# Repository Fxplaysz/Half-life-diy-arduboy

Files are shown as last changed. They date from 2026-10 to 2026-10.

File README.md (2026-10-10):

# Half-life-diy-arduboy
Hello everyone, this is my repository for my diy arduboy. Here you'll find the pcb and the 3d models later on.
I have made this DIY arduboy because i like mini handheld game consoles and electronics. This DIY Arduboy is very easy to build and can be made by anyone easily.

Aruduboy is a open source game console made by Kevin Bates. He has opensourced his console and made it easier for anyone to build it and have fun with it. I remember a few years back i tried making it by myself but i failed in doing so because of the technicalities in building it. So i've decided to make this project to let anyone make a DIY Arduboy easily and have fun while doing it.

It was made using KiCad and with the help of the internet. 
I made it in 2 days in the span of 5 hours in the 2 days.

# Features
* 0.96 SPI OLED display
* ISP pins for easy programming
* Buzzer for audio
* Flash chip to store more then 500+ games
* RGB LED
* *Silent* SMD push button switches. Good for long term gaming.

# Instructions
* Flash [Arduboy bootloader](https://github.com/MrBlinky/Arduboy-homemade-package) using the ISP header and a [usb asp](https://robu.in/product/usbasp-avr-programming-device-for-atmel-proccessors/)
* Upload games using the cart builder from MrBlinky [Arduboy-Python-Utilities](https://github.com/MrBlinky/Arduboy-Python-Utilities)
* Start Playing with it!

  - *More detailed instructions will be uploaded later*
    
# Photos
These are some of the photos of my PCBs.
1) PCB with smd mounted flash chip.
- Front
diy_ardubo_front

- Back
diy_ardubo_back

* PCB Lay out


2) PCB with support for flash module.
- Front
diy_ardubo_flash_module_front

- Back
diy_ardubo_flash_module_back

* PCB Lay out
  

   - [DIY Arduboy with Flash Module support](https://github.com/Fxplaysz/Half-life-diy-arduboy/blob/main/diy_ardubo_flash_module.pdf)
   - [DIY Arduboy with SMD flash chip](https://github.com/Fxplaysz/Half-life-diy-arduboy/blob/main/diy_ardubo.pdf)

The flash module version supports the addition of a flash module instead of using smd flash chip. Its mainly through hole components making it easier to build and use it.

The SMD version is a little slimmer then the flash module version but its hard to solder without hot air gun. So the choice is yours to build. 

Anyone Interested in building it can check my [BOM list](https://github.com/Fxplaysz/Half-life-diy-arduboy/blob/main/BOM.md). Feel free to ask questions.
Have fun everyone!

**Firmware Credit:** The test firmware used for this project is [Back to the Jungle](https://github.com/eried/ArduboyBackToTheJungle) created by **eried**.

* **Arduboy community:** https://community.arduboy.com/

* **Arduboy:** https://www.arduboy.com/

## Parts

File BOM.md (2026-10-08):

# DIY arduboy – bill of materials

<!-- Generated by Half Life from project cmuv6l7gq0e3701smizq8m7ku. Edits here are overwritten on the next sync. -->
<!-- Generated: 2026-10-08T20:18:28.352Z -->

> [!NOTE]
> This parts list is mirrored from [Half Life](https://halflife.hackclub.com). Editing it here will not change the platform's copy, and the next sync overwrites this file.

| Week | Tier | Parts funding |
| --- | --- | --- |
| Week 1 | Tier 1 | $30.00 |

| Part | What it's for | Qty | Unit | Total | Vendor |
| --- | --- | --- | --- | --- | --- |
| [0.96 OLED Display Module - SPI/I2C - 128x64 - 7 Pin Blue](https://robu.in/product/0-96-oled-display-module-spi-i2c-128x64-7-pin-blue/) | For the display of my arduboy | 2 | $2.47 | $4.94 | [GENERIC](https://robu.in/product/0-96-oled-display-module-spi-i2c-128x64-7-pin-blue/) |
| [Pro Micro Type C Microcontroller](https://robu.in/product/pro-micro-type-c-microcontroller-development-board-for-arduino/) | The main microcontroller of my diy arduboy | 2 | $5.57 | $11.14 | [GENERIC](https://robu.in/product/pro-micro-type-c-microcontroller-development-board-for-arduino/) |
| [XL-5050RGBC](https://robu.in/product/1-month-warranty-193/) | The rgb light of my arduboy | 5 | $0.08 | $0.40 | [GENERIC](https://robu.in/product/1-month-warranty-193/) |
| [100nf 50v Disc Capacitor](https://robu.in/product/100nf-50v-disc-capacitor/) | To smooth out the voltage and protect the flash chip from voltage spikes | 11 | $0.01 | $0.11 | [GENERIC](https://robu.in/product/100nf-50v-disc-capacitor/) |
| [BC557 PNP Transistor](https://robu.in/product/bc557-pnp-transistor-pack-of-20/) | To make the cs driver setup. | 12 | $0.02 | $0.24 | [GENERIC](https://robu.in/product/bc557-pnp-transistor-pack-of-20/) |
| [Female header pins](https://robu.in/product/fh2-54-09-10pzd-xunpu-plugin1x10-pin-2-54mm-female-headers-rohs/) | To connect the oled display and arduino pro micro with the components. | 5 | $0.20 | $1.00 | [GENERIC](https://robu.in/product/fh2-54-09-10pzd-xunpu-plugin1x10-pin-2-54mm-female-headers-rohs/) |
| [10K resistor](https://robu.in/product/mfr-25frf52-10k-yageo-metal-film-resistors-10k%cf%89-250mw-%c2%b1100ppm-%e2%84%83-%c2%b11-plugind2-4xl6-3mm-through-hole-resistors-rohs/) | To bring down the voltage for the flash chip | 5 | $0.03 | $0.15 | [Yageo](https://robu.in/product/mfr-25frf52-10k-yageo-metal-film-resistors-10k%cf%89-250mw-%c2%b1100ppm-%e2%84%83-%c2%b11-plugind2-4xl6-3mm-through-hole-resistors-rohs/) |
| [SMD Tactile Switches](https://robu.in/product/1-month-warranty-1138/) | The buttons of my diy arduboy. | 20 | $0.12 | $2.40 | [SHOUHAN](https://robu.in/product/1-month-warranty-1138/) |
| [W25Q128 breakout flash chip](https://robu.in/product/w25q128-large-capacity-flash-storage-module/) | The flash chip to hold the games | 2 | $1.85 | $3.70 | [GENERIC](https://robu.in/product/w25q128-large-capacity-flash-storage-module/) |
| [USB ASP](https://robu.in/product/usbasp-avr-programming-device-for-atmel-proccessors/) | For programming and flashing the bootloader of the arduino pro micro | 1 | $2.06 | $2.06 | [GENERIC](https://robu.in/product/usbasp-avr-programming-device-for-atmel-proccessors/) |
| [Male header pins](https://robu.in/product/2-54mm-1x40-pin-male-single-row-straight-short-header-strip-pack-of-3/) | To make the pinouts for the battery connector and other connectors | 2 | $0.09 | $0.18 | [GENERIC](https://robu.in/product/2-54mm-1x40-pin-male-single-row-straight-short-header-strip-pack-of-3/) |
| [1k ohm resistor](https://quartzcomponents.com/products/1k-ohm-1-4-watt-resistor-with-1-tolerance-pack-of-10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) | to make the cs driver chip (connecting resistor to bc557) | 1 | $0.10 | $0.10 | [GENERIC](https://quartzcomponents.com/products/1k-ohm-1-4-watt-resistor-with-1-tolerance-pack-of-10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) |
| [5V boost module](https://robu.in/product/xl3608-boost-module-5v/) | To boost the voltage of the 3.7v batteries to power up my diy arduboy | 2 | $0.52 | $1.04 | [GENERIC](https://robu.in/product/xl3608-boost-module-5v/) |
| [Slide switch](https://robu.in/product/slide-switch-sk-17b/) | Slide switch to turn off or on the diy arduboy | 5 | $0.04 | $0.20 | [Jinchen Electronics](https://robu.in/product/slide-switch-sk-17b/) |
| [Passive buzzers](https://robu.in/product/1-month-warranty-1248/) | Buzzers to produce sound from my diy arduboy | 1 | $0.51 | $0.51 | [GENERIC](https://robu.in/product/1-month-warranty-1248/) |
| [Male to female jumper cables](https://robu.in/product/male-to-female-jumper-wires-40pcs-20cm/) | To debugg my diy arduboy | 1 | $0.51 | $0.51 | [GENERIC](https://robu.in/product/male-to-female-jumper-wires-40pcs-20cm/) |
| [AVR ISP 10 Pin to 6 Pin Adapter Board](https://robu.in/product/avr-isp-10-pin-to-6-pin-adapter-board/) | Adapter for flashing the bootloader and programming | 1 | $0.30 | $0.30 | [GENERIC](https://robu.in/product/avr-isp-10-pin-to-6-pin-adapter-board/) |
| [24AWG Single core teflon wire](https://robu.in/product/24awg-single-core-teflon-wire-red/) | For connecting passive components like the battery with the booster | 3 | $0.14 | $0.42 | [GENERIC](https://robu.in/product/24awg-single-core-teflon-wire-red/) |
| **Parts subtotal** | — | — | — | **$29.40** | — |
| **Tax & shipping** | — | — | — | **$0.00** | — |
| **Total** | — | — | — | **$29.40** | — |

$0.60 left of the tier's funding.

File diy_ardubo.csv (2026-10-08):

Id | Designator | Footprint | Quantity | Designation | Supplier and ref
1 | BZ1 | PinHeader_1x02_P2.54mm_Vertical | 1 | Buzzer
2 | C1 | C_Disc_D3.8mm_W2.6mm_P2.50mm | 1 | C
3 | D2 | LED_Inolux_IN-P55TATRGB_PLCC6_5.0x5.5mm_P1.8mm | 1 | Inolux_IN-P55TATRGB
4 | J1 | PinHeader_2x01_P2.54mm_Vertical | 1 | Conn_02x01
5 | J2 | PinSocket_1x07_P2.54mm_Vertical | 1 | Conn_01x07_Pin
6 | J3 | PinHeader_2x03_P2.54mm_Vertical | 1 | Conn_02x03_Odd_Even
7 | J4 | PinHeader_1x01_P2.54mm_Vertical | 1 | Conn_01x01_Pin
8 | Q1 | TO-92_Inline | 1 | BC557
9 | R1, R2, R3 | R_Axial_DIN0207_L6.3mm_D2.5mm_P7.62mm_Horizontal | 3 | R
10 | SW1, SW2, SW3, SW4, SW5, SW6, SW7 | SW_Push_1TS009xxxx-xxxx-xxxx_6x6x5mm | 7 | SW_Push
11 | SW8 | SW_Slide-03_Wuerth-WS-SLTV_10x2.5x6.4_P2.54mm | 1 | SW_SPDT
12 | U1 | ProMicro | 1 | ProMicro
13 | U2 | SOIC-8_5.3x5.3mm_P1.27mm | 1 | W25Q128JVS

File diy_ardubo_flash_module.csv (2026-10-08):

Id | Designator | Footprint | Quantity | Designation | Supplier and ref
1 | A, B, Down, RESET, SW3, SW4, Up | SW_Push_1TS009xxxx-xxxx-xxxx_6x6x5mm | 7 | SW_Push
2 | BZ1 | PinHeader_1x02_P2.54mm_Vertical | 1 | Buzzer
3 | C1 | C_Disc_D3.8mm_W2.6mm_P2.50mm | 1 | C
4 | D1 | LED_Inolux_IN-P55TATRGB_PLCC6_5.0x5.5mm_P1.8mm | 1 | Inolux_IN-P55TATRGB
5 | J1 | PinHeader_2x01_P2.54mm_Vertical | 1 | Conn_02x01
6 | J2 | PinSocket_1x07_P2.54mm_Vertical | 1 | Conn_01x07_Pin
7 | J3 | PinHeader_2x03_P2.54mm_Vertical | 1 | Conn_02x03_Odd_Even
8 | J4 | PinSocket_1x06_P2.54mm_Vertical | 1 | Conn_01x06_Pin
9 | J5 | PinHeader_1x01_P2.54mm_Vertical | 1 | Conn_01x01_Pin
10 | Q1 | TO-92_Inline | 1 | BC557
11 | R1, R2, R3 | R_Axial_DIN0207_L6.3mm_D2.5mm_P7.62mm_Horizontal | 3 | R
12 | SW8 | SW_Slide-03_Wuerth-WS-SLTV_10x2.5x6.4_P2.54mm | 1 | SW_SPDT
13 | U1 | ProMicro | 1 | ProMicro

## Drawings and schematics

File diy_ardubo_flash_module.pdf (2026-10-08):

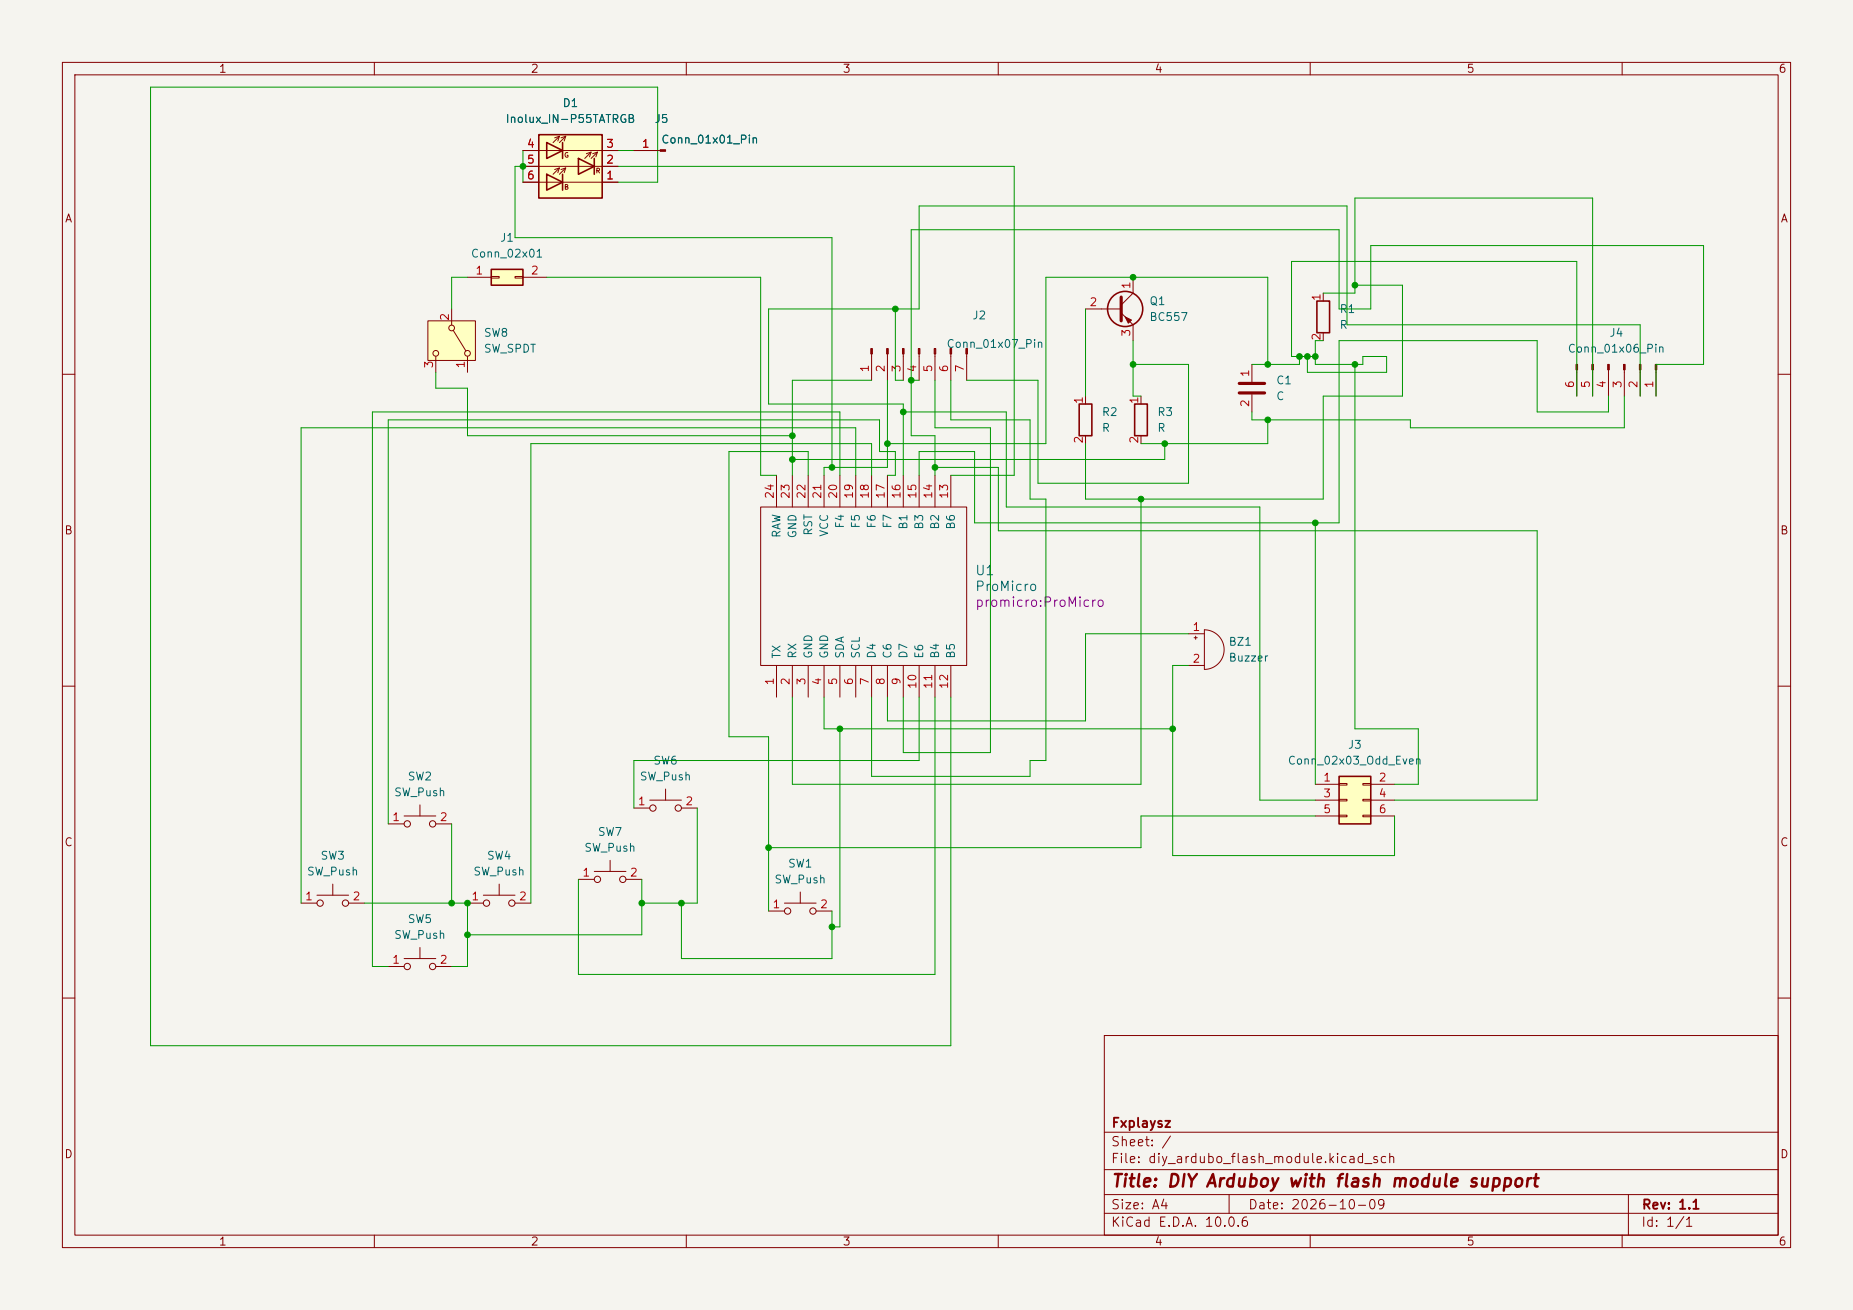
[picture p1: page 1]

5 5 | 2 2

9 E6 10 B4 11 B5 12 B6 13 B2 14 B3 15 B1 16 F7 17 F6 18 F5 19 F4 20 VCC 21 RST 22 GND 23 RAW 24

Fxplaysz
Sheet: /
File: diy_ardubo_flash_module.kicad_sch
Title: DIY Arduboy with flash module support

Size: A4 | Rev: 1.1
KiCad E.D.A. 10.0.6 | Id: 1/1

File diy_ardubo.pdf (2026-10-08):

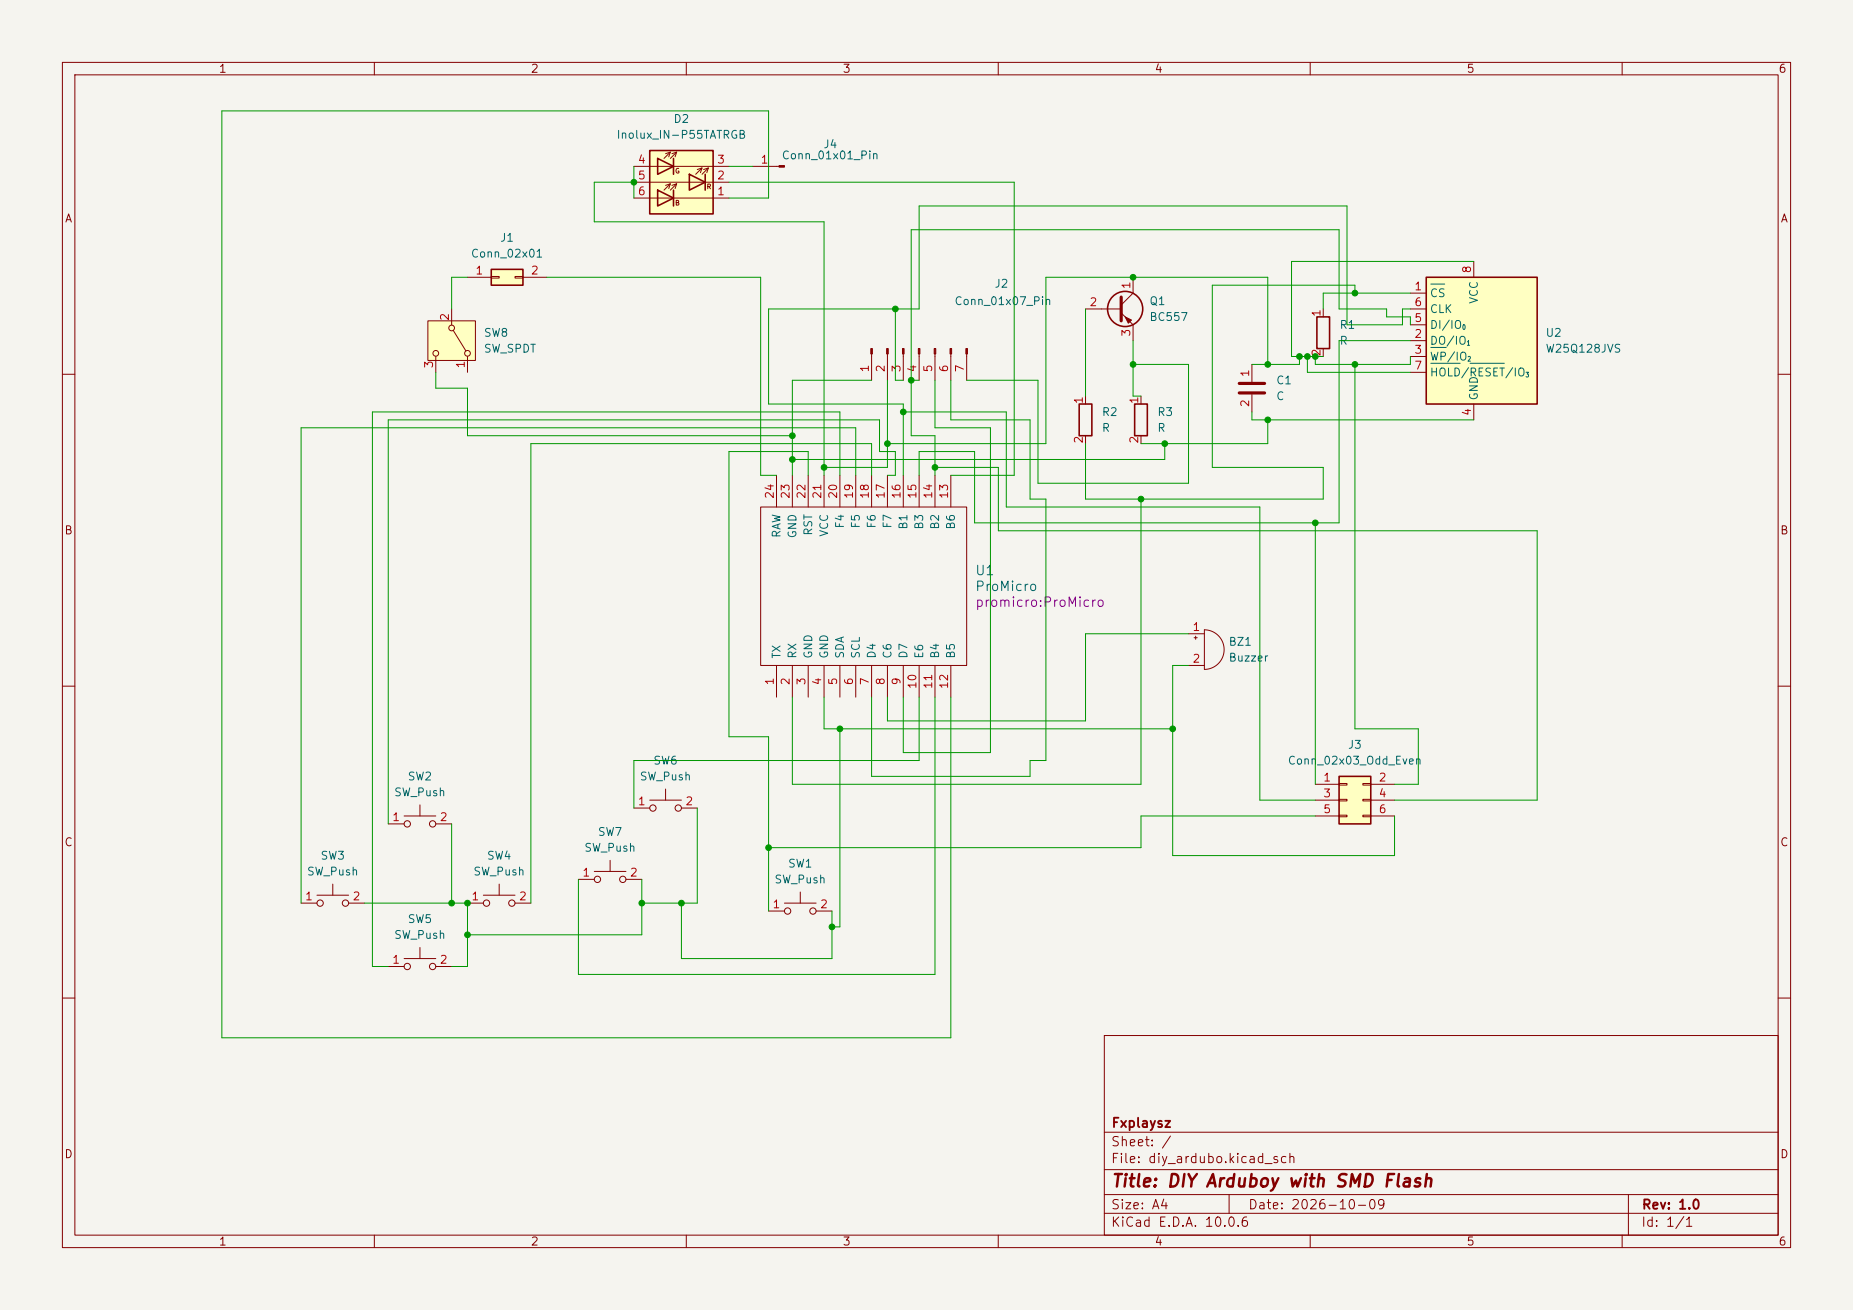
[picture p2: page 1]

4 DI/IO0 5 CLK 6 HOLD/RESET/IO3 7 VCC

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

Fxplaysz
Sheet: /
File: diy_ardubo.kicad_sch
Title: DIY Arduboy with SMD Flash

Size: A4 | Rev: 1.0
KiCad E.D.A. 10.0.6 | Id: 1/1

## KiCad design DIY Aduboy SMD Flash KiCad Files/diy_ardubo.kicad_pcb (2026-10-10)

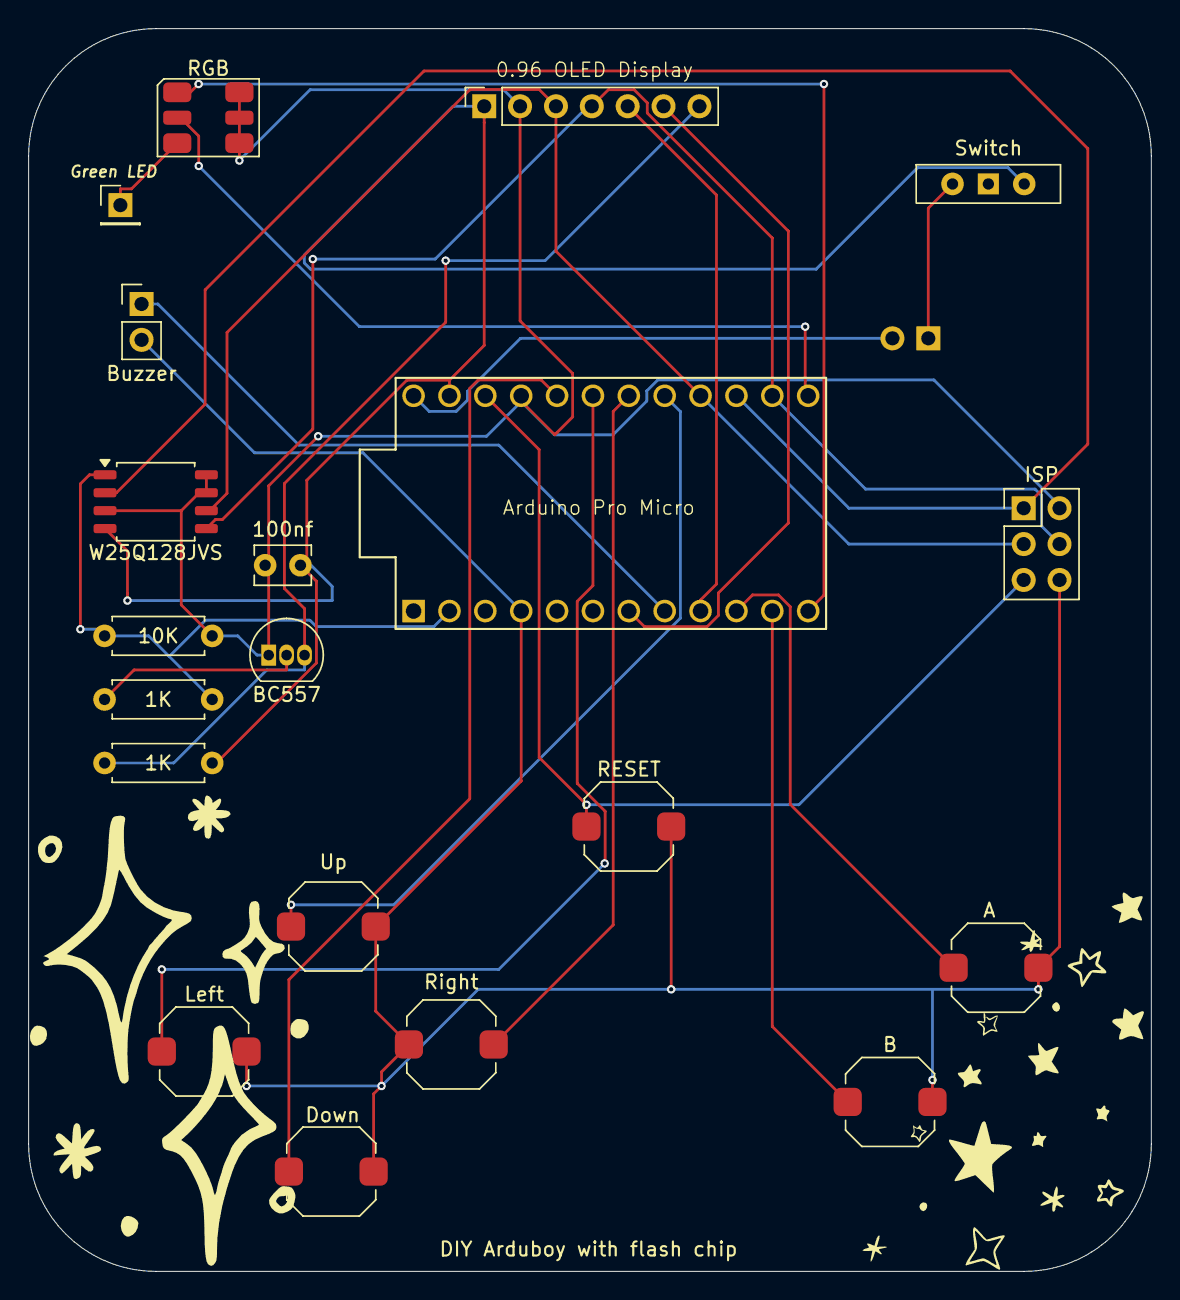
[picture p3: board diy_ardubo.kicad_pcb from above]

Board: 2 copper layers, 79.5 x 88.0 mm, 21 parts (1 on the bottom side), 24 nets.

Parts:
100nf: C; C_Disc_D3.8mm_W2.6mm_P2.50mm
B: SW_Push; SW_Push_1TS009xxxx-xxxx-xxxx_6x6x5mm
BZ1: Buzzer; PinHeader_1x02_P2.54mm_Vertical
Green LED: Conn_01x01_Pin; PinHeader_1x01_P2.54mm_Vertical
ISP: Conn_02x03_Odd_Even; PinHeader_2x03_P2.54mm_Vertical
J1: Batt. Connector; PinHeader_2x01_P2.54mm_Vertical
J2: Conn_01x07_Pin; PinSocket_1x07_P2.54mm_Vertical
Left: SW_Push; SW_Push_1TS009xxxx-xxxx-xxxx_6x6x5mm
Q1: BC557; TO-92_Inline
R1: R2; R_Axial_DIN0207_L6.3mm_D2.5mm_P7.62mm_Horizontal
R2: R3; R_Axial_DIN0207_L6.3mm_D2.5mm_P7.62mm_Horizontal
R3: R; R_Axial_DIN0207_L6.3mm_D2.5mm_P7.62mm_Horizontal
RESET: SW_Push; SW_Push_1TS009xxxx-xxxx-xxxx_6x6x5mm
RGB: Inolux_IN-P55TATRGB; LED_Inolux_IN-P55TATRGB_PLCC6_5.0x5.5mm_P1.8mm
Right: SW_Push; SW_Push_1TS009xxxx-xxxx-xxxx_6x6x5mm
SW5, SW6: SW_Push; SW_Push_1TS009xxxx-xxxx-xxxx_6x6x5mm
Switch: SW_SPDT; SW_Slide-03_Wuerth-WS-SLTV_10x2.5x6.4_P2.54mm
U1: ProMicro
U2: W25Q128JVS; SOIC-8_5.3x5.3mm_P1.27mm
Up: SW_Push; SW_Push_1TS009xxxx-xxxx-xxxx_6x6x5mm

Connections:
unnamed: BZ1.1 (+), U1.8 (C6)
unnamed: B.2, BZ1.2 (-), ISP.6, Left.2, RESET.2, Right.1, SW5.2, SW6.2, U1.4 (GND), Up.2
unnamed: 100nf.1, ISP.2, J2.2 (VCC), Q1.1 (C), R1.2, RGB.4 (AG), RGB.5 (AR), RGB.6 (AB), U1.21 (VCC), U2.3 (~WP/IO_{2}), U2.7 (~HOLD/~RESET/IO_{3}), U2.8 (VCC)
unnamed: RGB.1 (KB), U1.12 (B5)
unnamed: Green LED.1 (Pin_1_1), RGB.3 (KG)
unnamed: RGB.2 (KR), U1.13 (B6)
unnamed: J1.1, Switch.2 (B)
unnamed: J1.2, U1.24 (RAW)
unnamed: J2.7 (CS), Q1.3 (E), R3.1
unnamed: ISP.3, J2.3 (D0), U1.16 (B1), U2.6 (CLK)
unnamed: ISP.4, J2.4 (D1), U1.14 (B2), U2.5 (DI/IO_{0})
unnamed: J2.6 (DC), U1.7 (D4)
unnamed: 100nf.2, J2.1 (GND), R3.2, Switch.3 (C), U1.23 (GND), U2.4 (GND)
unnamed: J2.5 (RES), U1.9 (D7)
unnamed: ISP.1, U1.15 (B3), U2.2 (DO/IO_{1})
unnamed: ISP.5, RESET.1, U1.22 (RST)
unnamed: Q1.2 (B), R2.1
unnamed: B.1, U1.11 (B4)
unnamed: SW6.1, U1.10 (E6)
unnamed: SW5.1, U1.20 (F4)
unnamed: Left.1, U1.19 (F5)
unnamed: Right.2, U1.18 (F6)
unnamed: U1.17 (F7), Up.1
unnamed: R1.1, R2.2, U1.2 (RX), U2.1 (~CS)

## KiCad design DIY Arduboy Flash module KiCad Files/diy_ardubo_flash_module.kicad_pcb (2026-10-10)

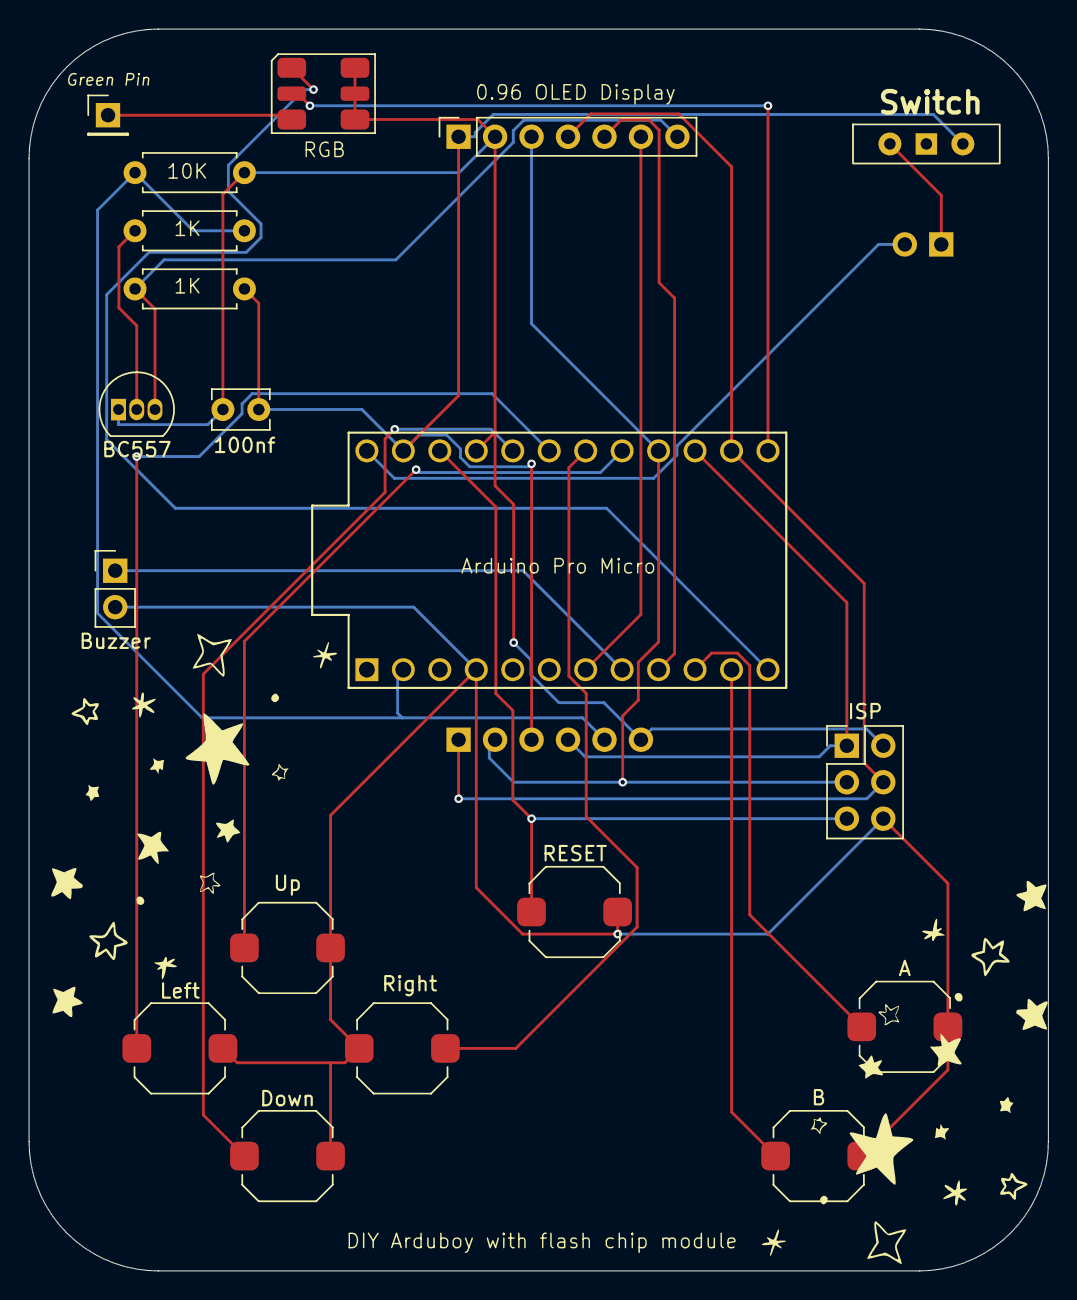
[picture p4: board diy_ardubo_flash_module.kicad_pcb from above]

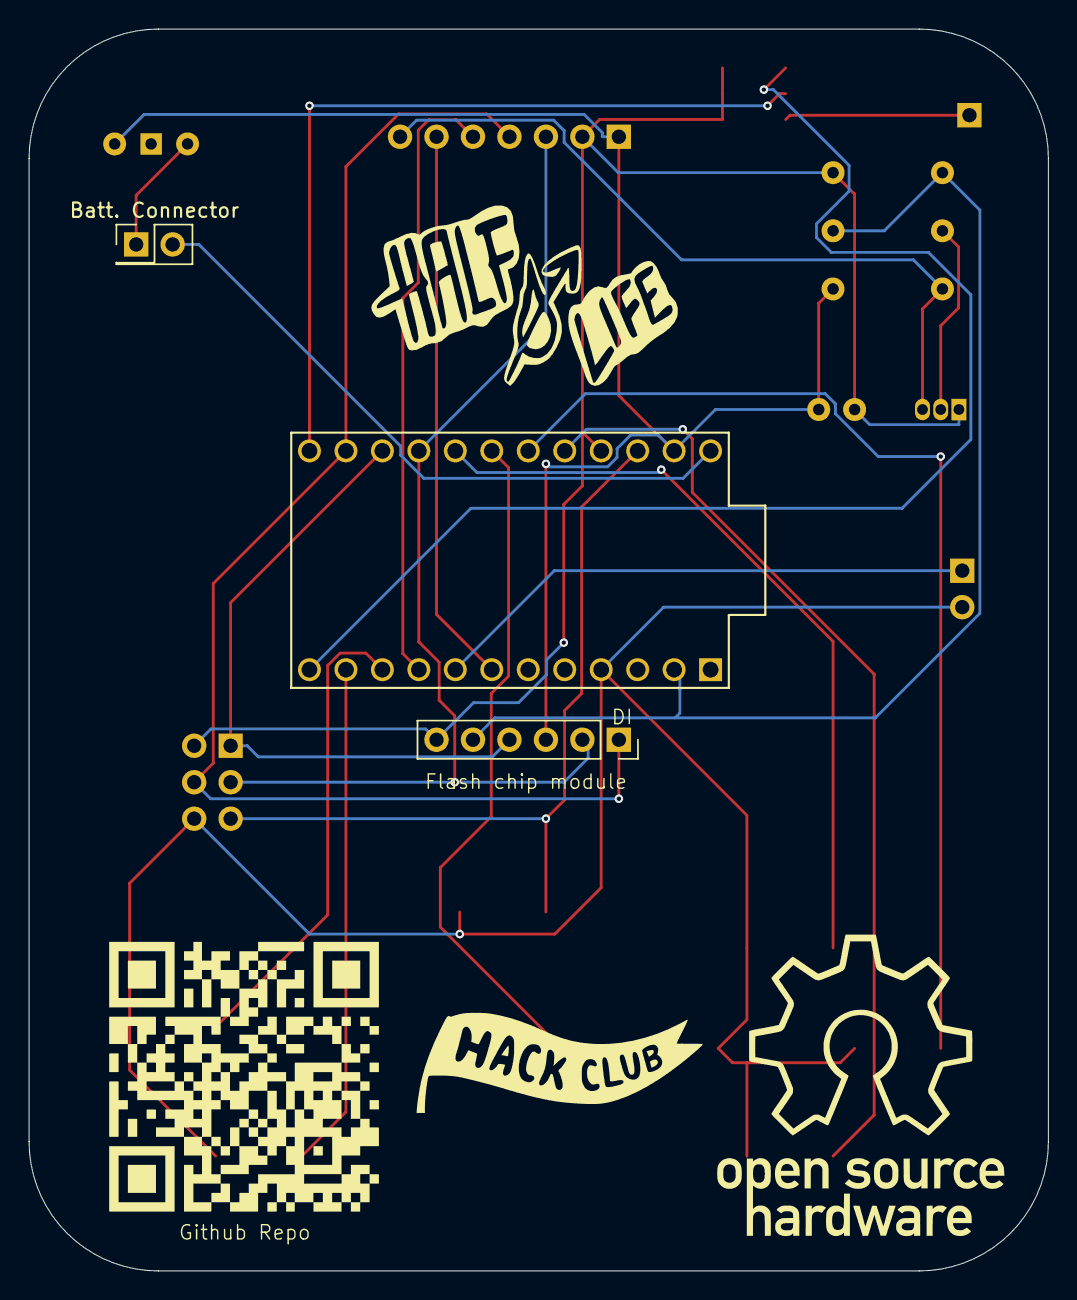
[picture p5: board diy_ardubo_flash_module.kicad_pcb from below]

Board: 2 copper layers, 71.0 x 86.5 mm, 21 parts (2 on the bottom side), 24 nets.

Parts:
100nf: C; C_Disc_D3.8mm_W2.6mm_P2.50mm
A: SW_Push; SW_Push_1TS009xxxx-xxxx-xxxx_6x6x5mm
B: SW_Push; SW_Push_1TS009xxxx-xxxx-xxxx_6x6x5mm
BZ1: Buzzer; PinHeader_1x02_P2.54mm_Vertical
Batt. Connector: Conn_02x01; PinHeader_2x01_P2.54mm_Vertical
D1: Inolux_IN-P55TATRGB; LED_Inolux_IN-P55TATRGB_PLCC6_5.0x5.5mm_P1.8mm
Down: SW_Push; SW_Push_1TS009xxxx-xxxx-xxxx_6x6x5mm
ISP: Conn_02x03_Odd_Even; PinHeader_2x03_P2.54mm_Vertical
J2: Conn_01x07_Pin; PinSocket_1x07_P2.54mm_Vertical
J4: Conn_01x06_Pin; PinSocket_1x06_P2.54mm_Vertical
J5: Conn_01x01_Pin; PinHeader_1x01_P2.54mm_Vertical
Q1: BC557; TO-92_Inline
R1, R2, R3: R; R_Axial_DIN0207_L6.3mm_D2.5mm_P7.62mm_Horizontal
RESET: SW_Push; SW_Push_1TS009xxxx-xxxx-xxxx_6x6x5mm
SW3, SW4: SW_Push; SW_Push_1TS009xxxx-xxxx-xxxx_6x6x5mm
SW8: SW_SPDT; SW_Slide-03_Wuerth-WS-SLTV_10x2.5x6.4_P2.54mm
U1: ProMicro
Up: SW_Push; SW_Push_1TS009xxxx-xxxx-xxxx_6x6x5mm

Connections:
unnamed: BZ1.1 (+), U1.8 (C6)
unnamed: A.2, B.2, BZ1.2 (-), Down.2, ISP.6, RESET.2, SW3.2, SW4.1, U1.4 (GND), Up.2
unnamed: 100nf.1, D1.4 (AG), D1.5 (AR), D1.6 (AB), ISP.2, J2.2 (VCC), J4.6, Q1.1 (C), R1.2, U1.21 (VCC)
unnamed: D1.1 (KB), U1.12 (B5)
unnamed: D1.3 (KG), J5.1 (Pin_1_1)
unnamed: D1.2 (KR), U1.13 (B6)
unnamed: Batt. Connector.1, SW8.2 (B)
unnamed: Batt. Connector.2, U1.24 (RAW)
unnamed: J2.7 (CS), Q1.3 (E), R3.1
unnamed: ISP.3, J2.3 (D0), J4.2, U1.16 (B1)
unnamed: ISP.4, J2.4 (D1), J4.1, U1.14 (B2)
unnamed: J2.6 (DC), U1.7 (D4)
unnamed: 100nf.2, J2.1 (GND), J4.3, R3.2, SW8.3 (C), U1.23 (GND)
unnamed: J2.5 (RES), U1.9 (D7)
unnamed: ISP.1, J4.4, U1.15 (B3)
unnamed: ISP.5, RESET.1, U1.22 (RST)
unnamed: J4.5, R1.1, R2.2, U1.2 (RX)
unnamed: Q1.2 (B), R2.1
unnamed: B.1, U1.11 (B4)
unnamed: A.1, U1.10 (E6)
unnamed: Down.1, U1.20 (F4)
unnamed: SW3.1, U1.19 (F5)
unnamed: SW4.2, U1.18 (F6)
unnamed: U1.17 (F7), Up.1

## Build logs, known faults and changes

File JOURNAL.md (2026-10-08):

# DIY arduboy – devlog

<!-- Generated by Half Life from project cmuv6l7gq0e3701smizq8m7ku. Edits here are overwritten on the next sync. -->
<!-- Generated: 2026-10-08T17:12:26.714Z -->

> [!NOTE]
> This devlog is mirrored from [Half Life](https://halflife.hackclub.com). Editing it here will not change the platform's copy, and the next sync overwrites this file.

> hello guys. im going to be making a diy arduboy. it will have a flashcart, and rgb led.

| Week | Tier | Hours logged | Entries |
| --- | --- | --- | --- |
| Week 1 | Tier 1 | 10.41h | 2 |

## Contents

1. [2026-10-05 – OMG i didn't know how to select the video recording screen properly so 1.5 minutes of the footage is blank..](#2026-10-05-omg-i-didnt-know-how-to-select-the-video-recordin)
2. [2026-10-08 – Hellooo,](#2026-10-08-hellooo)

## Design

### 2026-10-05 – OMG i didn't know how to select the video recording screen properly so 1.5 minutes of the footage is blank..

**5.13h**

OMG i didn't know how to select the video recording screen properly so 1.5 minutes of the footage is blank..
BUT today was such a good day.. I learned how to use kicad for the first time by myself without the help of ai, just youtube lol.

Today i designed the schematics and routed the components. I was thinking to give up when first designing the schematics because it was kinda hard 😭. But i was eventually able to put it all together very nicely..

I still have'nt thought about the battery charging properly. Most propably the best idea will be to use the batt header pin and use voltage booster. Tommorow i'll think about it







[Timelapse](https://lookout.hackclub.com/api/media/92bdcc72-10ba-4308-9f3c-e9f16743c447/video.mp4)

### 2026-10-08 – Hellooo,

**5.28h**

Hellooo,
Today i decided to finish up on my DIY arduboy. First of all, i made so many mistakes with the schematic 😔😬. SO i fixed it all up.
 I made one additional board which supports flash module instead of smd soldering the flash chip.
I added SMD 5050 RGB  LEDs. (one extra pin header to take green led lead from the cpu since pin is not exposed)
 The issues i faced was fixing the CS and DI, DO pins from the flash module. Hopefully the fixes i did today will work 😭.

I hope that i get selected. If i get selected i will buy hot air station and soldering iron from the project store ☺️





[Timelapse](https://lookout.hackclub.com/api/media/29710981-dd2a-423c-9943-9e168afc07e6/video.mp4)

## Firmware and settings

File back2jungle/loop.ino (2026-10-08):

void loop()
{
  if (!arduboy.nextFrame())
    return;

  switch (gameState)
  {
    case GameState::Splash:
      doIntroTheme();
      doSplash();

    case GameState::MainMenu:
      doIntroTheme();
      doMainMenu();
      break;

    case GameState::Intro:
      doIntro();

    case GameState::SkipIntro:
      specialCarBonus = false;
      score = 0;
      currentLevel = 0;
      lives = STARTLIVES;
      gameState = GameState::StartLevel;
      break;

    case GameState::End:
      if (!tunes.playing())
        tunes.playScore(gameovertheme);

      arduboy.clear();
      if (wait < millis())
      {
        // Show gameover text
        arduboy.setCursor(12, 25);
        arduboy.setTextSize(2);
        arduboy.print("GAME OVER");
        arduboy.setTextSize(1);
      }

      if (millis() > debounce)
      {
        // Show score
        arduboy.setCursor(0, arduboy.height() - 7);
        arduboy.print("Score: ");
        arduboy.print(score);

        arduboy.setCursor(0, 0);
        arduboy.print("Hi: ");
        arduboy.print(highscore);

        while (!arduboy.notPressed(A_BUTTON + B_BUTTON)); // Wait for button release

        arduboy.setCursor(arduboy.width() - 40, 0);
        arduboy.print("Retry");
        arduboy.setCursor(arduboy.width() - 34, arduboy.height() - 7);
        arduboy.print("Menu");
        arduboy.display();

        do
        {
          if ( waitForButton(false))
            gameState = GameState::MainMenu;
          else if ( waitForButton(false, true, arduboy.height()))
            gameState = GameState::SkipIntro;
        } while (gameState == GameState::End);

        while (!arduboy.notPressed(A_BUTTON + B_BUTTON)); // Wait for button release
        tunes.stopScore();
      }
      arduboy.display();

      break;

    case GameState::Win:
      doWinDialog();
      gameState = GameState::StartLevel;
      break;

    case GameState::GameOver:
    case GameState::Lose:
      if (--lives <= 0)
      {
        animateDialog(monkeybig, gameover2);
        arduboy.delayShort(1000);
        gameState = GameState::End;
        wait =  millis() + (arduboy.audio.enabled() ? 2000 : 0);
        debounce = wait + 2000;
      }
      else
      {
        animateDialog(monkeybig, gameover1, true);
        waitForButton();
        gameState = GameState::StartLevel;
      }
      break;

    case GameState::StartLevel:
      for (byte i = 0; i < enemiesMax; i++)
        enemiesPos[i] = arduboy.height();

      tunes.playScore(levelintro);
      playerx = INVALID;
      playery = INVALID;
      currentFrame = 0;
      specialCar = BYTE_MAX;

    case GameState::StartLevelIntro:
      if (playerx != INVALID)
        playerx += 0.15;

      if (playerx > 3)
      {
        gameState = GameState::Playing;
        currentLevelTime = millis();
      }

    default: // Level
      if (!tunes.playing() && gameState == GameState::Playing)
        tunes.playScore(level);

      gameState = doGame(gameState == GameState::Playing);

#ifdef DEBUG
      Serial.print("PLAYING, NEXT STATE: ");
      Serial.println(gameState);
#endif
      break;
  }
}

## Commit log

2026-10-08 DIY Arduboy with support for flash module
    [diy_ardubo_flash_module.kicad_pcb]
2026-10-08 DIY Arduboy with flash chip
    [diy_ardubo.kicad_pcb]
2026-10-08 DIY Arduboy with flash chip support
    [diy_ardubo.kicad_sch]
2026-10-08 diy_ardubo.kicad_pcb
    DIY Arduboy with flash chip support
    [diy_ardubo.kicad_pcb]
2026-10-08 DIY Arduboy with support for flash chip
    [diy_ardubo.kicad_pcb]
2026-10-08 BOM of diy_ardubo_flash_module
    [diy_ardubo_flash_module.csv]
2026-10-08 BOM of diy_ardubo
    [diy_ardubo.csv]
2026-10-08 Schematics of DIY arduboy with SMD flash
2026-10-08 Schematics of DIY arduboy with flash module support
2026-10-10 Updated PCB
    Added graphics
2026-10-10 KiCad Files (for flash module options)
    [diy_ardubo_flash_module.kicad_pcb, diy_ardubo_flash_module.kicad_sch]
2026-10-10 KiCad Files (for flash module option)
2026-10-10 KiCad Files (for SMD flash option)
    [diy_ardubo.kicad_pcb, diy_ardubo.kicad_sch]
2026-10-10 Update README.md
    Updated Images.
    New Graphics added to boards
2026-10-10 Update README.md
    Added Front and back images of PCB
2026-10-11 Updated Schematics
2026-10-11 Schematics of DIY Arduboy with flash module support
    Updated some wirings and connection methods
2026-10-11 Schematics of DIY Arduboy with SMD Flash support
    Updated some wirings and connection options
2026-10-11 Updated Schematics
    Fixed ground pin issue with switch
2026-10-11 BOM of the Arduboy flash module version
2026-10-11 BOM of Arduboy SMD version
2026-10-11 BOM of Arduboy Flash module version
2026-10-16 Update README.md ( added BOM )
2026-10-16 Added BOM.csv
2026-10-16 update bom
2026-10-18 Sync DIY arduboy enclosure from Half Life
